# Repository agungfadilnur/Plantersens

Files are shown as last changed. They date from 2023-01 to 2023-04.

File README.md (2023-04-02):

# Lora RF95 Shield Arduino
Prototype Lora RF95 Shield on Arduino Uno for PlanterSens

## Testing PCB v1.0
I make a prototype shield RF95 by cheap production 😁

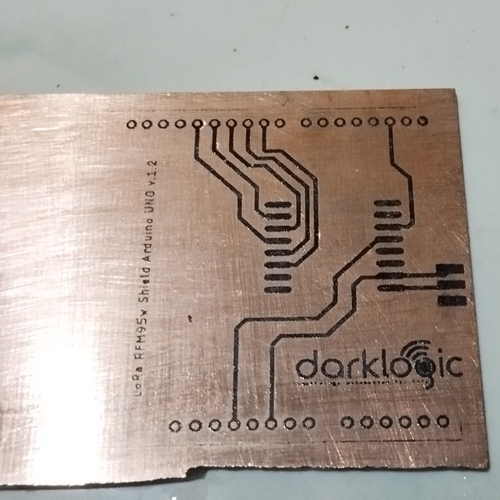
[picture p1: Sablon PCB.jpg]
Sablon PCB


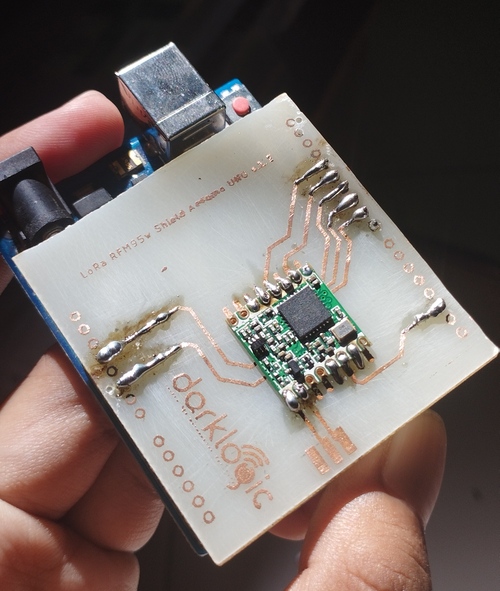
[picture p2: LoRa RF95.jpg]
Lora RF95


test shield lora

For more information about project at  [Lora RF95 Shield](https://agungfadilnur.github.io)

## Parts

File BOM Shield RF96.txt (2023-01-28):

R1 10K
R2 100K
R3 100K
C1 100nF
C2 0.1uF
C3 10uF
IC 74HC4050

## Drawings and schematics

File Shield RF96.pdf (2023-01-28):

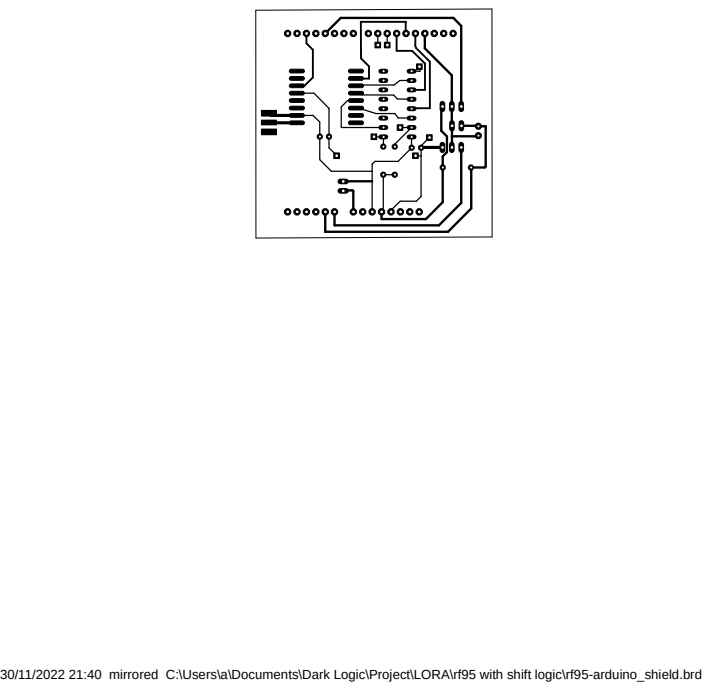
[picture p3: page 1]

30/11/2022 21:40 mirrored C:\Users\a\Documents\Dark Logic\Project\LORA\rf95 with shift logic\rf95-arduino_shield.brd

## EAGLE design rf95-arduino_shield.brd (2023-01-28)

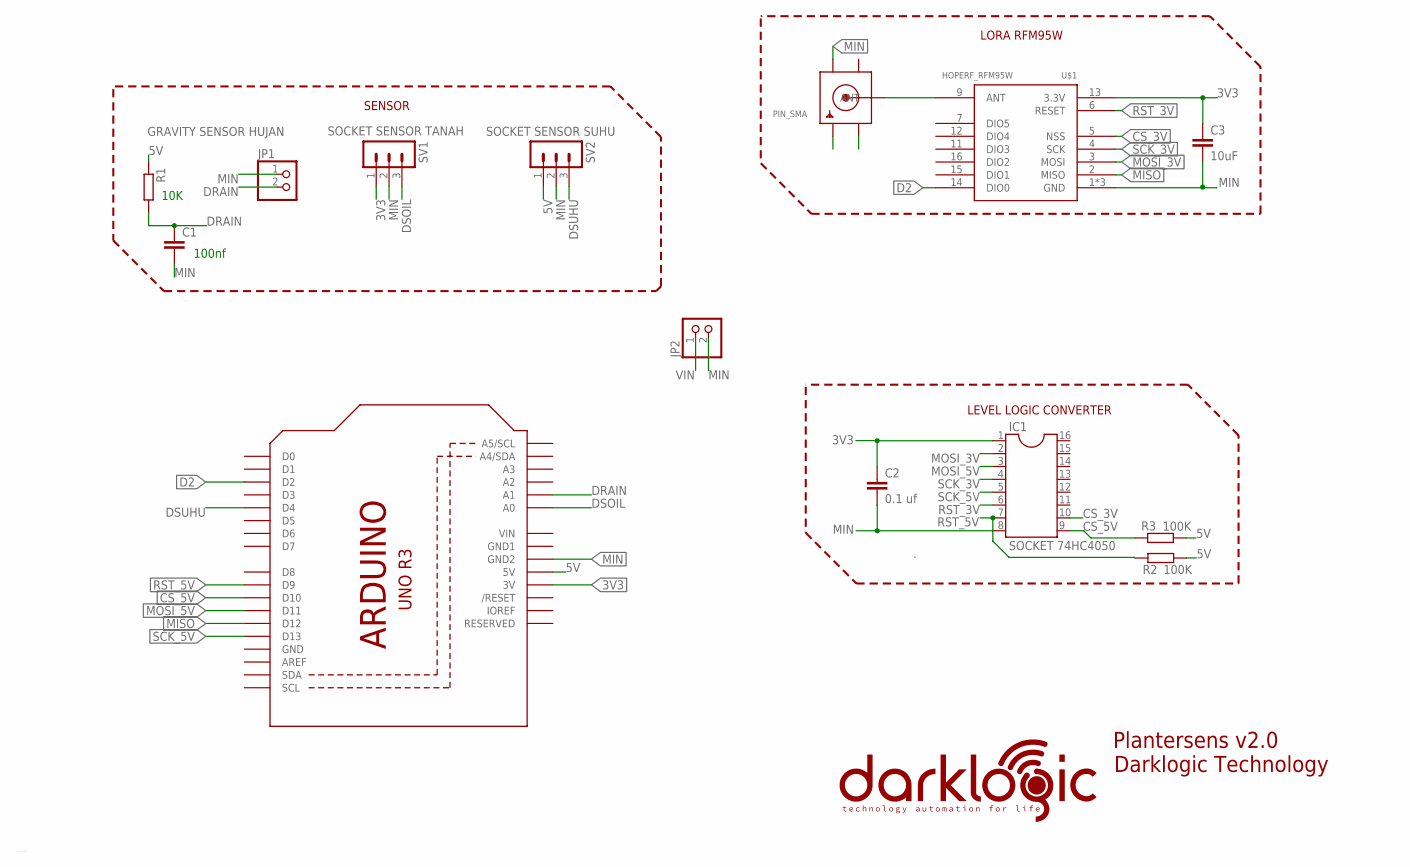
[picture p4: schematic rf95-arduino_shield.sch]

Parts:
C1: C2.5/2; C2.5-2
C2: 0.1 uf; C025-024X044
C3: 10uF; C025-024X044
IC1: SOCKET 74HC4050; SOCKET-16
JP1: GRAVITY SENSOR HUJAN; 1X02
JP2: PINHD-1X2; 1X02
PIN_SMA: SMACONNECTOR_EDGE; SMA_EDGELAUNCH
R1: R-EU_0204/7; 0204/7
R2, R3: 100K; 0204/7
SV1: SOCKET SENSOR TANAH; MA03-1
SV2: SOCKET SENSOR SUHU; MA03-1
U1: ARDUINOR3-BPLACE
U$1: HOPERF_RFM95W

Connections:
3V3: C2.1, C3.1, IC1.1, SV1.1, U1.3V, U$1.13 (3.3V)
5V: R1.1, R2.1, R3.2, SV2.1, U1.5V
ANT: PIN_SMA.P (ANT), U$1.9 (ANT)
CS_3V: IC1.10, U$1.5 (NSS)
CS_5V: IC1.9, R3.1, U1.D10
D2: U1.D2, U$1.14 (DIO0)
DRAIN: C1.1, JP1.2, R1.2, U1.A1
DSOIL: SV1.3, U1.A0
DSUHU: SV2.3, U1.D4
GND1: U1.GND1
GND3: PIN_SMA.GND@2 (GND3)
MIN: C1.2, C2.2, C3.2, IC1.8, JP1.1, JP2.2, PIN_SMA.GND@1 (GND4), SV1.2, SV2.2, U1.GND, U1.GND2, U$1.1 (GND), U$1.8 (GND), U$1.10 (GND)
MISO: U1.D12, U$1.2 (MISO)
MOSI_3V: IC1.2, U$1.3 (MOSI)
MOSI_5V: IC1.3, U1.D11
RST_3V: IC1.6, U$1.6 (RESET)
RST_5V: IC1.7, R2.2, U1.D9
SCK_3V: IC1.4, U$1.4 (SCK)
SCK_5V: IC1.5, U1.D13
VIN: JP2.1, U1.VIN

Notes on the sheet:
10K
100nf
LEVEL LOGIC CONVERTER
LORA RFM95W
SENSOR
Plantersens v2.0
Darklogic Technology
C:/Users/a/Documents/Dark Logic/Project/LORA/darklogic hitam copy.bmp

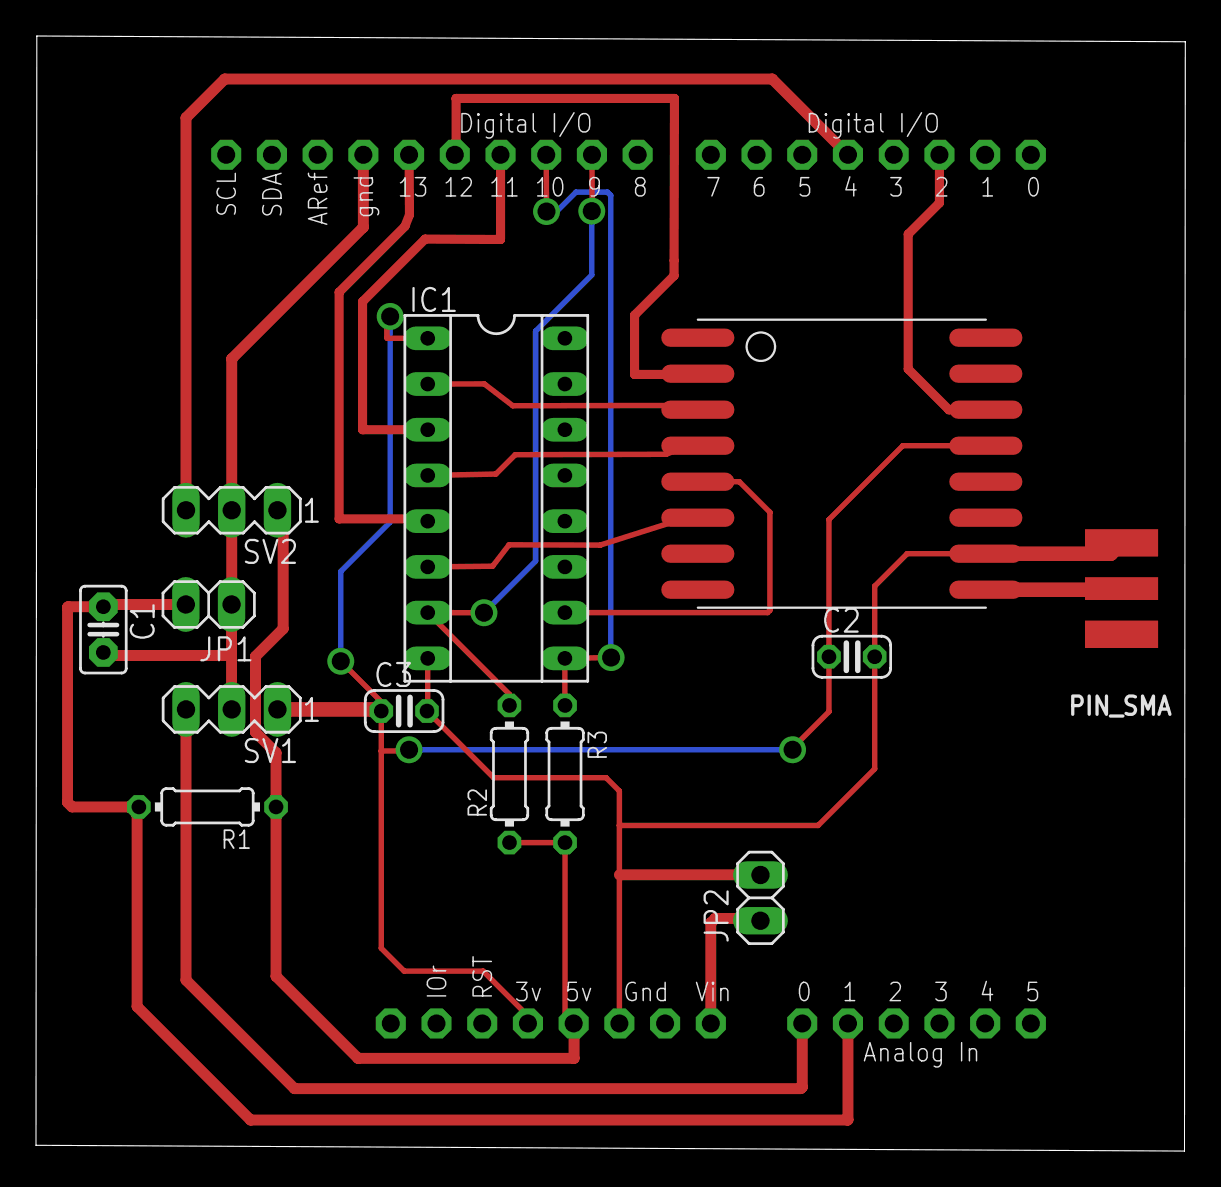
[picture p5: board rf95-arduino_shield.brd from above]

Board: 2 copper layers, 63.9 x 61.9 mm, 14 parts (0 on the bottom side), 18 nets.
